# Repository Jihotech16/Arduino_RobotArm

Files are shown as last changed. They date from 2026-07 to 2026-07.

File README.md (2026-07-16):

# ARM-01 Robot Arm Controller

Arduino Uno 로봇팔을 Arduino IDE 시리얼 모니터와 Web Serial 웹앱 양쪽에서 제어하는 프로젝트입니다.

**웹 컨트롤러:** https://jihotech16.github.io/Arduino_RobotArm/

## 배선

- 관절 서보 3개 신호선: D3 (세 서보가 같은 각도로 동시 동작)
- 그리퍼 서보 신호선: D5
- 28BYJ-48 ULN2003: IN1→D8, IN2→D9, IN3→D10, IN4→D11
- 서보와 스테퍼는 별도 5V 전원을 권장하며, 외부 전원 GND와 Arduino GND를 반드시 공통 연결합니다.

## Arduino IDE에서 먼저 테스트

1. `arduino/RobotArmController/RobotArmController.ino`를 Arduino IDE에서 엽니다.
2. 보드 `Arduino Uno`, 올바른 포트를 선택하고 업로드합니다.
3. 시리얼 모니터를 `115200 baud`로 엽니다. 줄바꿈 설정은 무엇이든 괜찮습니다.
4. 아래 글자 하나를 입력하고 전송합니다.

| 키 | 동작 |
|---|---|
| W / S | 관절 서보 3개 함께 올리기 / 내리기 |
| A / D | 스테퍼 베이스 왼쪽 / 오른쪽 |
| Q / E | 그리퍼 열기 / 닫기 |
| R | 관절과 그리퍼를 홈 각도로 이동 |

전원을 켜거나 R 키를 누르면 관절 서보 3개와 그리퍼 서보가 모두 90°로 이동합니다.

## 웹앱

Chrome 또는 Edge에서 웹앱을 열고 `USB 연결`을 누른 뒤 Arduino Uno 포트를 선택합니다. 키보드 키를 누르고 있는 동안 명령이 반복 전송됩니다. Arduino IDE 시리얼 모니터가 포트를 사용 중이면 먼저 닫아야 웹앱에서 연결할 수 있습니다.

웹의 3D 디지털 트윈은 실제 3MF 출력 부품의 메시를 사용하며, Arduino가 전송하는 `STATE` 값으로 베이스, 연결 관절, 그리퍼 자세를 실시간 시각화합니다. 버튼을 누르면 화면이 먼저 즉시 반응하고 Arduino의 다음 `STATE` 응답으로 실제 명령 상태를 보정합니다. 마우스 드래그로 시점을 회전하고 휠로 확대·축소할 수 있습니다. 현재 구성은 센서 피드백이 아닌 명령 상태 기반 시뮬레이션입니다.

`main` 브랜치에 변경사항을 올리면 GitHub Actions가 정적 사이트를 다시 빌드하여 GitHub Pages에 자동 배포합니다.

> 베이스 스테퍼에는 원점 센서가 없으므로 R 키가 베이스의 물리적 원점을 찾지는 않습니다. 정확한 홈 복귀가 필요하면 리미트 스위치를 추가해야 합니다.

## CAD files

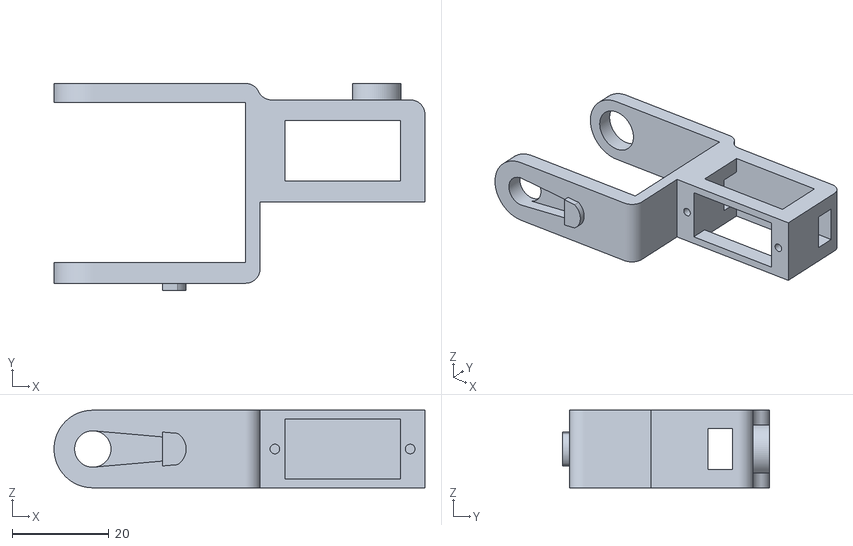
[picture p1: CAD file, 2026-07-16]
public/models/robot-arm/joint-1.stl
76.5 x 42.7 x 16.0

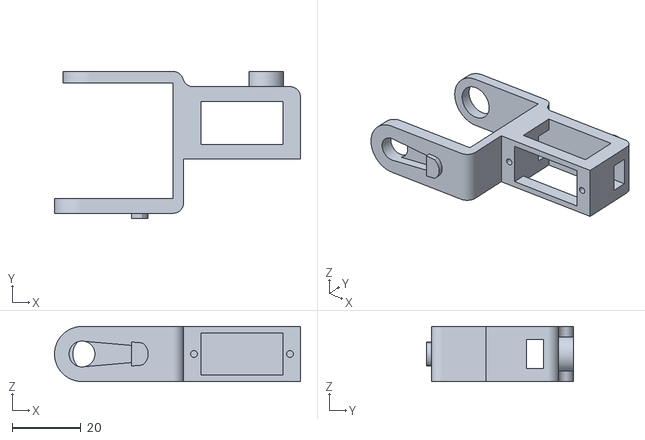
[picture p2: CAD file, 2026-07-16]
public/models/robot-arm/joint-2.stl
71.5 x 42.7 x 16.0

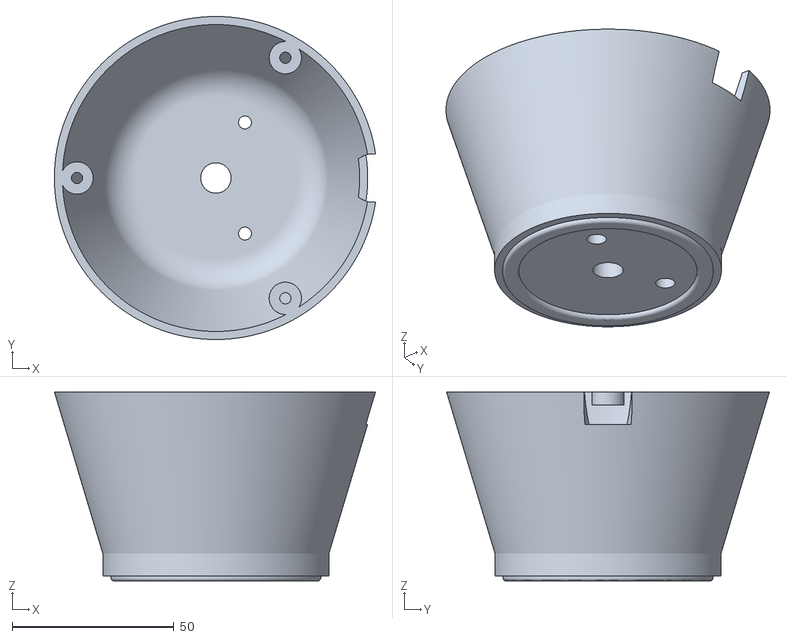
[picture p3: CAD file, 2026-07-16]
public/models/robot-arm/base-body.stl
99.4 x 100.0 x 58.5

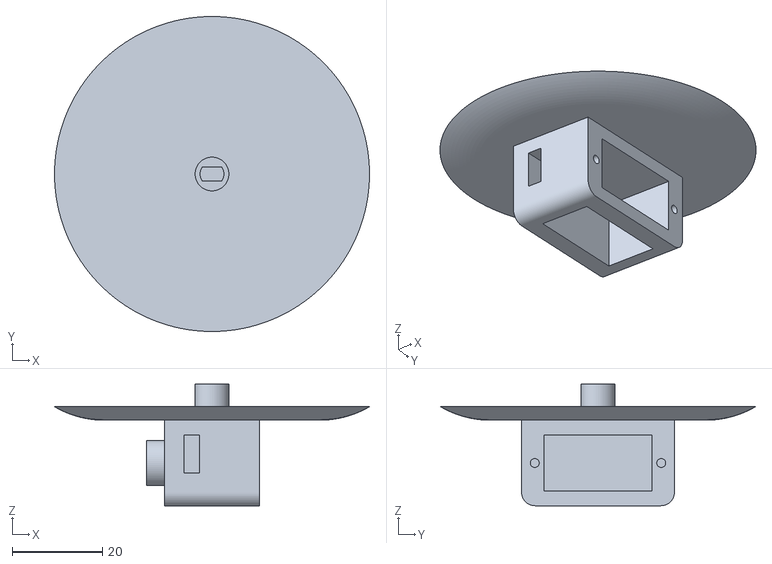
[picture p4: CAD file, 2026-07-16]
public/models/robot-arm/stepper-hat.stl
70.0 x 70.0 x 27.0

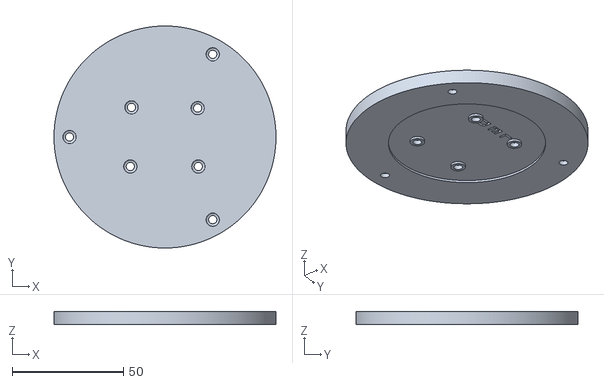
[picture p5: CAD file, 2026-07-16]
public/models/robot-arm/base-bottom.stl
100.0 x 100.0 x 6.00

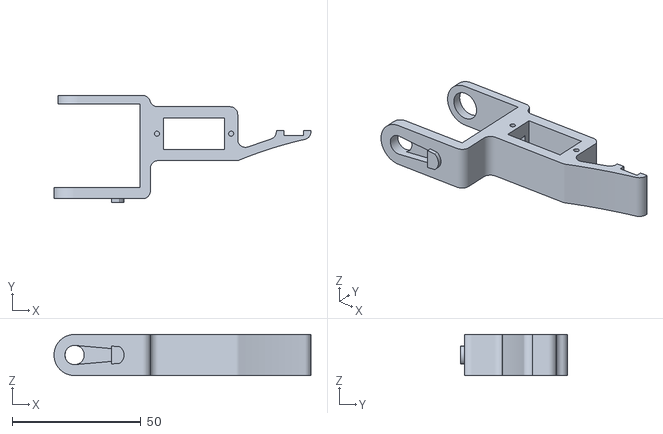
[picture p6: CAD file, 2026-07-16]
public/models/robot-arm/gripper.stl
100.0 x 41.7 x 16.0

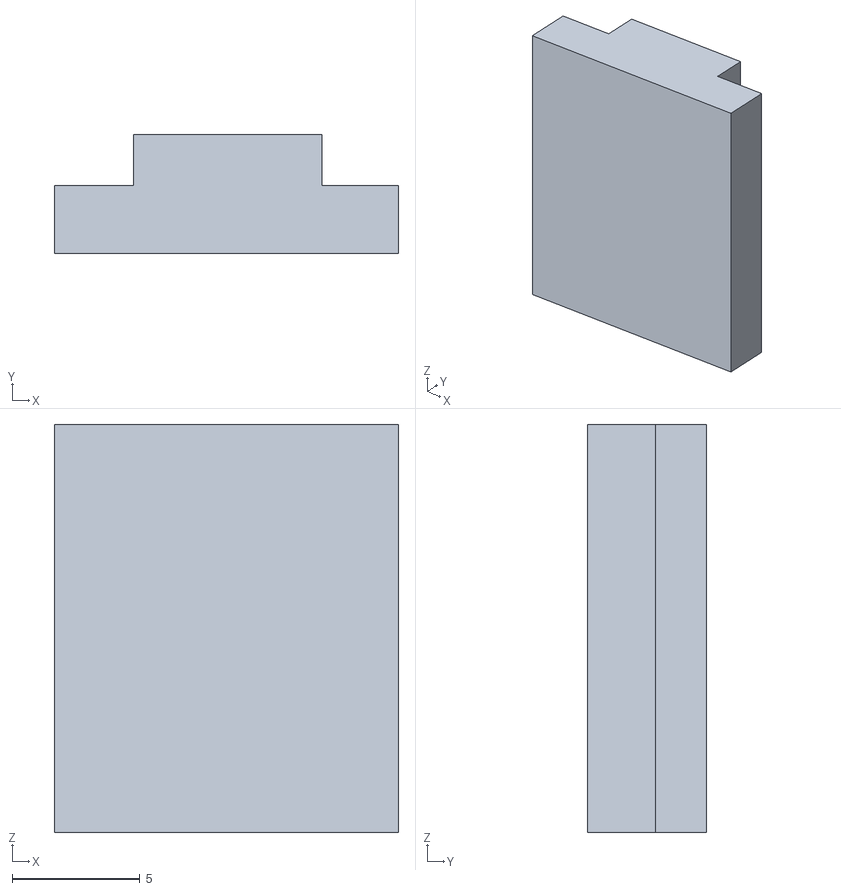
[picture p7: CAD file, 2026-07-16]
public/models/robot-arm/claw-insert.stl
13.5 x 4.68 x 16.0

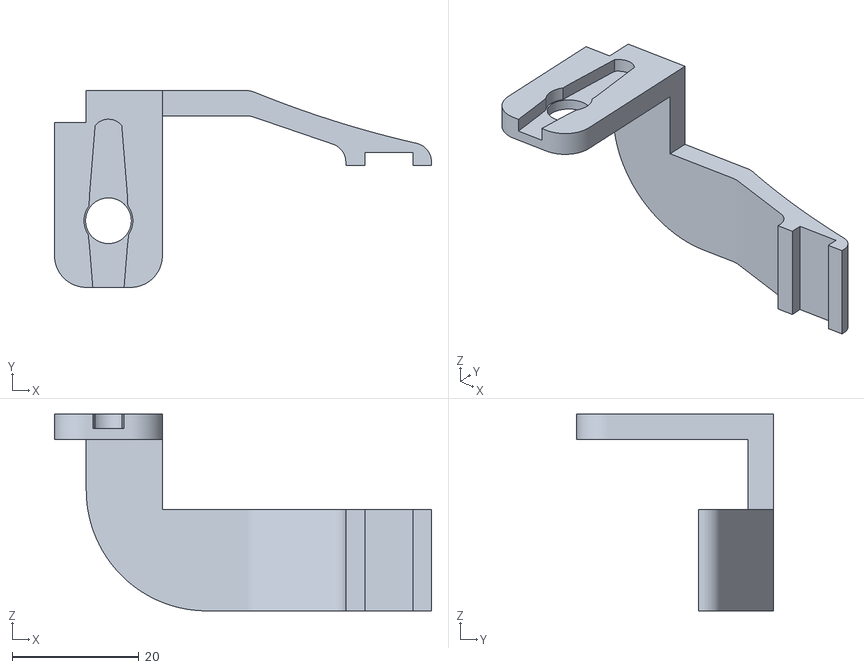
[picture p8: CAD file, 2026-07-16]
public/models/robot-arm/claw.stl
59.4 x 31.0 x 31.0

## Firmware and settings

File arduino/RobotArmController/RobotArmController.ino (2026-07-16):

#include <Servo.h>
#include <Stepper.h>

// ---- Pin configuration ----
const byte ARM_SERVO_PIN = 3;      // Joint servos 1, 2, 3: signal wires together
const byte GRIPPER_SERVO_PIN = 5;
const byte STEPPER_IN1 = 8;
const byte STEPPER_IN2 = 9;
const byte STEPPER_IN3 = 10;
const byte STEPPER_IN4 = 11;

// 28BYJ-48 + ULN2003: change this value if your motor is different.
const int STEPS_PER_REVOLUTION = 2048;
const int STEPPER_CHUNK = 8;
const int SERVO_INCREMENT = 2;
const int ARM_MIN = 15;
const int ARM_MAX = 165;
const int GRIPPER_MIN = 10;
const int GRIPPER_MAX = 170;
const int ARM_HOME = 90;
const int GRIPPER_HOME = 90;

Servo armServos;
Servo gripperServo;

// Stepper library order for a 28BYJ-48 is IN1, IN3, IN2, IN4.
Stepper baseStepper(STEPS_PER_REVOLUTION,
                    STEPPER_IN1, STEPPER_IN3, STEPPER_IN2, STEPPER_IN4);

int armAngle = ARM_HOME;
int gripperAngle = GRIPPER_HOME;
long basePosition = 0;

void reportState() {
  Serial.print(F("STATE "));
  Serial.print(basePosition);
  Serial.print(' ');
  Serial.print(armAngle);
  Serial.print(' ');
  Serial.println(gripperAngle);
}

void moveArm(int amount) {
  armAngle = constrain(armAngle + amount, ARM_MIN, ARM_MAX);
  armServos.write(armAngle);
}

void moveGripper(int amount) {
  gripperAngle = constrain(gripperAngle + amount, GRIPPER_MIN, GRIPPER_MAX);
  gripperServo.write(gripperAngle);
}

void moveBase(int amount) {
  baseStepper.step(amount);
  basePosition += amount;
}

void goHome() {
  // Servo home only. The stepper has no position sensor, so base zeroing
  // requires a limit switch and is intentionally not attempted here.
  armAngle = ARM_HOME;
  gripperAngle = GRIPPER_HOME;
  armServos.write(armAngle);
  gripperServo.write(gripperAngle);
}

void handleCommand(char command) {
  switch (tolower(command)) {
    case 'w': moveArm(+SERVO_INCREMENT); break;
    case 's': moveArm(-SERVO_INCREMENT); break;
    case 'a': moveBase(-STEPPER_CHUNK); break;
    case 'd': moveBase(+STEPPER_CHUNK); break;
    case 'q': moveGripper(-SERVO_INCREMENT); break;
    case 'e': moveGripper(+SERVO_INCREMENT); break;
    case 'r': goHome(); break;
    case 'x': return; // Stop marker; useful for future expansion.
    default: return;  // Ignore Enter, newline, spaces, and unknown input.
  }
  reportState();
}

void setup() {
  Serial.begin(115200);
  armServos.attach(ARM_SERVO_PIN);
  gripperServo.attach(GRIPPER_SERVO_PIN);
  baseStepper.setSpeed(10);
  goHome();
  delay(350);
  Serial.println(F("READY ARM-01"));
  reportState();
}

void loop() {
  while (Serial.available() > 0) {
    handleCommand((char)Serial.read());
  }
}

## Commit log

2026-07-16 Build ARM-01 Web Serial controller
2026-07-16 Deploy robot arm controller with GitHub Pages
2026-07-16 Use real 3MF parts in digital twin
    [base-body.stl, base-bottom.stl, claw-insert.stl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]
2026-07-16 Fix live twin response and 90 degree home
    [base-body.stl, joint-1.stl, joint-2.stl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]
2026-07-16 Flip base housing and stepper hat
2026-07-16 Recenter stepper hat mesh (#5)
    Center the imported Stepper Hat geometry before assembling it on the robot base.
2026-07-16 Make linked joints bend front to back (#6)
    Use the horizontal joint axes so W/S pitches the arm forward and backward.
2026-07-16 Reassemble all CAD parts (#7)
    Clear retained print-bed offsets before placing every robot part in the assembly hierarchy.
2026-07-16 Fix middle joint direction (#8)
    Make J2 follow the same linked-servo direction as J1 and J3.
2026-07-16 Fix left gripper orientation (#9)
    Mirror the left claw on the correct left/right axis.
